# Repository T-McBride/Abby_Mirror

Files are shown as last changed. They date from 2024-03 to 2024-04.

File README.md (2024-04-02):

# Abby's Mirror: About
<p>
Dear Abby,

This project is the collective effort of your Aunt Jill, Uncle, Dave, Jim, Monica, and myself.<br>
May it bring you many years of joy.
</p>
<br>

<hr>

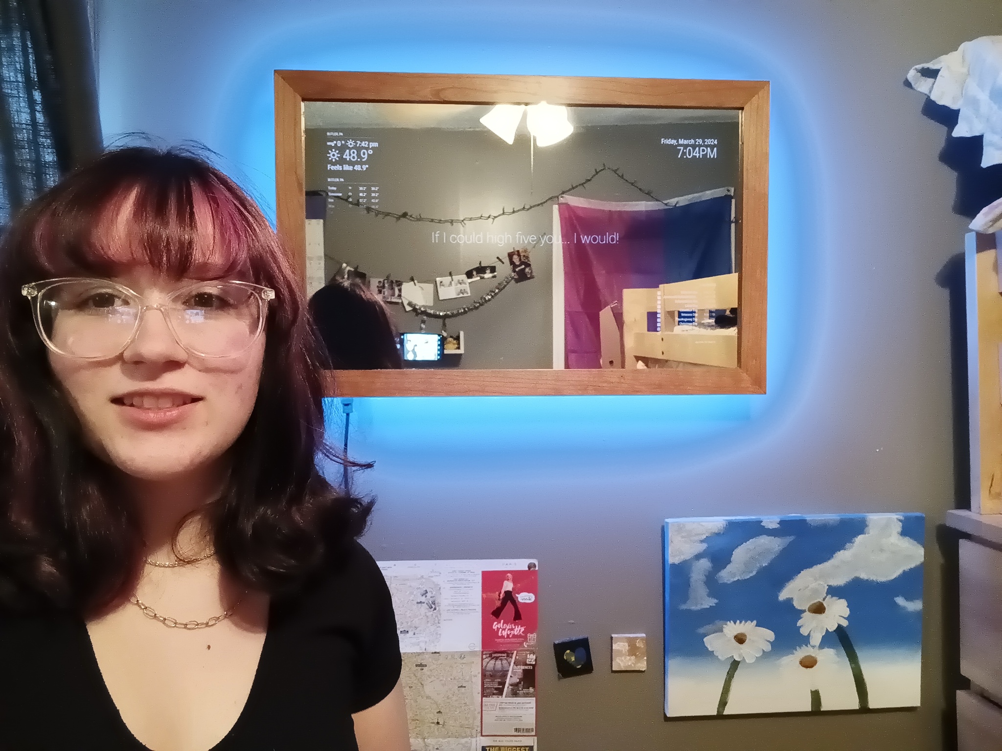
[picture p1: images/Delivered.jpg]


*pic of delivery day for posterity*

<hr>

## Pages

  * [Quick Start](./QuickStart.md) (start here to get the basics)
  * [Guide](./Guide.md) Detailed informaiton about using all features of your mirror
  * [Build Log](./BuildLog.md) This page shows a history of how your mirror came to be
  * [Print files](./Print.md) stl files of 3D printed parts used
  * The rest of this page contains basic information about your mirror.
<hr>

## Hardware
This section documents the hardware used to create your mirror.
| Object | Description | Ref | Pic | 
| :--- | :---: | :---: | :---: |
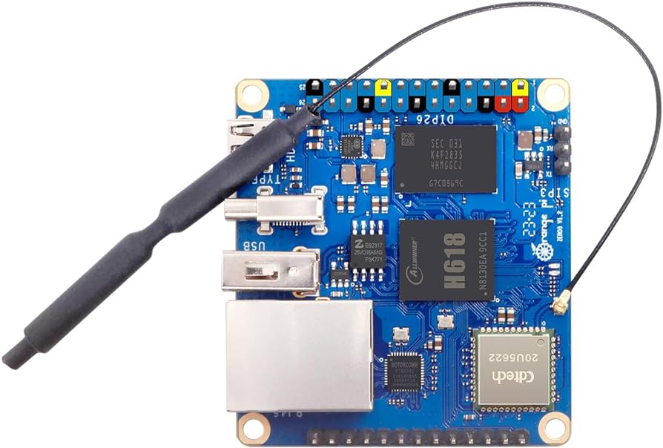
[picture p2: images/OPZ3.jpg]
| Orange Pi Zero 3  | Hardware / CPU | [Orangepi website](http://www.orangepi.org/html/hardWare/computerAndMicrocontrollers/details/Orange-Pi-Zero-3.html) |  |
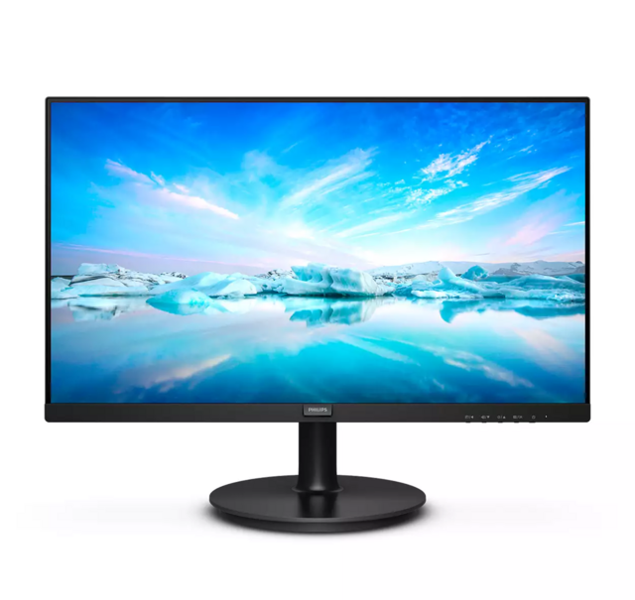
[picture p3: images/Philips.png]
| Philips 27" monitor | Monitor | [Philips V-line](https://www.usa.philips.com/c-p/271V8L_27/monitor-lcd-monitor) |  |
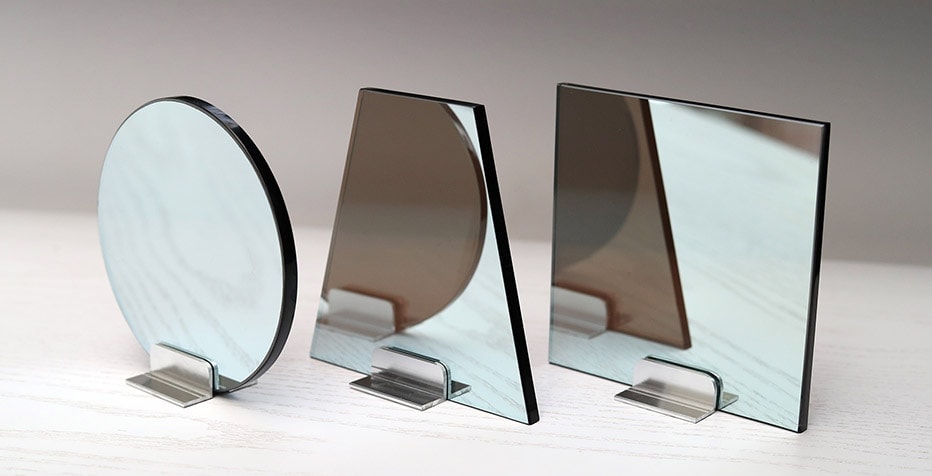
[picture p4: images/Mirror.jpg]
| One way mirror glass | Provided by Alderfer | [Alderfer](https://alderferglass.com/) |  | 
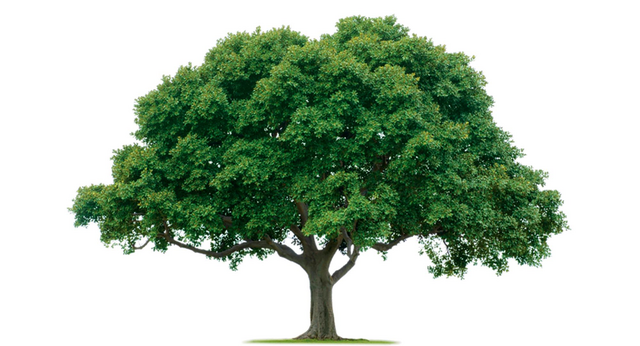
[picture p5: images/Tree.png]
| Frame | Poplar frame with Cherry trim | [trees](https://www.arborday.org/trees/treeguide) |  |  
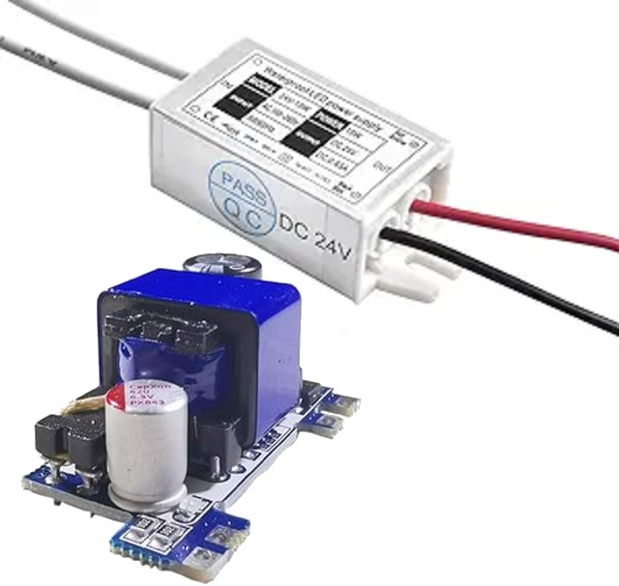
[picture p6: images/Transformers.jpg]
| Transformers | 120v to [5v & 24v] | [120v to 24v](https://www.amazon.com/24V-LED-Power-Supply-Transformer/dp/B09DKR1F71) <br> [120v to 5v](https://www.amazon.com/Converter-Module-Universal-Isolated-Switching/dp/B08ZSW2PP8) |  |
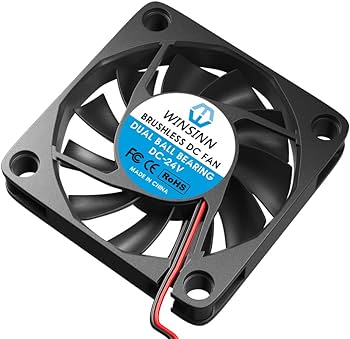
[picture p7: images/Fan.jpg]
| Fans | 24v 60mm fans | [Fans](https://www.amazon.com/WINSINN-Brushless-Computer-Motherboard-Graphics/dp/B07R3WCKCX) |  | 
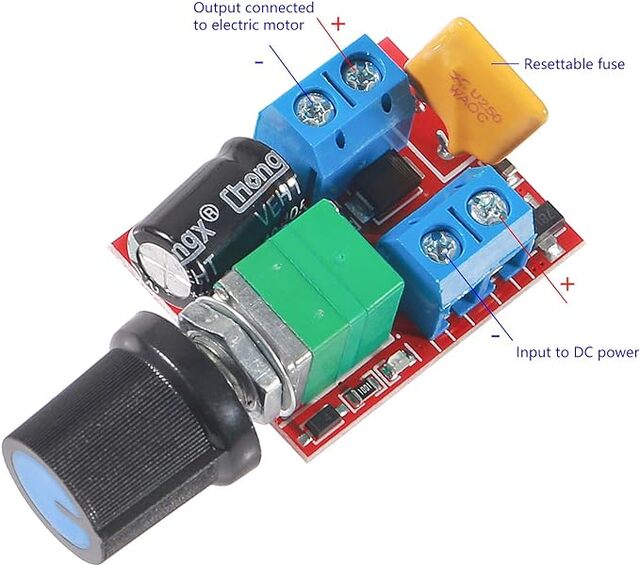
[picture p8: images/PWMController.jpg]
| Fan controller | PWM controller | [PWM Controller](https://www.amazon.com/Motor-Controller-Control-Switch-Dimmer/dp/B08T5TJWYH) |  |

<hr>

## Software
This is the software used to create and augment your mirror.
| Object | Description | Ref | 
| :--- | :--- | :--- |
| Operating System | Debian Bookworm | [Orange Pi OS Downloads](http://www.orangepi.org/html/hardWare/computerAndMicrocontrollers/service-and-support/Orange-Pi-Zero-3.html) | 
| MagicMirror | Primary application | https://magicmirror.builders/ | 
| Samba | Windows file sharing | https://www.samba.org/ |

<hr>

## Magic Mirror Config
This section describes how your mirror has been configured (default). This configuration can be chagned and customized however desired.

### Modules 
Your mirror has several modules that extend it's functionality, below is the list of currently installed modules. There are many modules available, read more about modules [via this link](https://github.com/MichMich/MagicMirror/wiki/3rd-party-modules).
| Module | Desc |  
| :--- | :--- |
| MMM-Remote | Provides a web interface to interact and manage your mirror | 
| MMM-Scheduler | Schedule module visibility, brightness, etc | 
| Weather | Current and forecast | 
| Clock | it's a clock | 
| MMM-DailyBibleVerse | Verse of the day from BibleGateway.com | 
| MMM-RAIN-MAP | Shows a radar map when it's raining | 
| Compliments Plus | Abby's favorite plugin, originally from here https://github.com/hangorazvan but appears to be abandoned.  | 
| MMM-BackgroundSlideshow | Mirror wallpaper, rotates from samba share folder | 

### Default Module Config and Layout
This section describes how the default modules are configured.
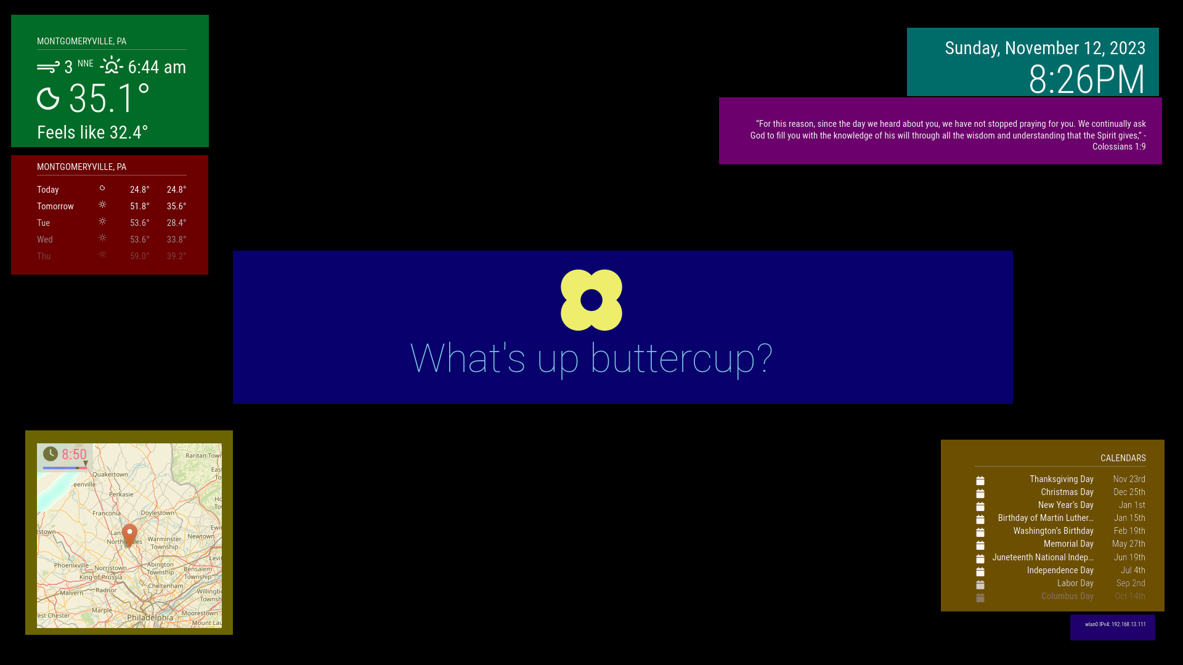
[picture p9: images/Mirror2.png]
mirror2


| Module | Location (default) | Color | Displays | 
| :--- | :--- | :--- | :--- |
| Current weather | top left | green | always |
| Forecast | top left | red | always |
| Rain Map | lower left | yellow | when raining |  
| Clock | top right | cyan | always | 
| Daily verse | top right | magenta | Sunday | 
| Compliments plus | center | blue | always |
| Calendar | lower right | orange | daily 6:00AM to 10:00PM | 
| IP address | lower right | purple | always (until turned off) |
| * | * | * | all modules dimmed to 40% at 10PM | 

Next: Read the [usage guide](Guide.md)

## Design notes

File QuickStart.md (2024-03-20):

# Abby's Mirror: Quick Start 

On the back of your mirror was a letter with a QR code that brought you hear. This letter also contained the passwords you will need as you follow this guide. 

<hr>

## Initial Startup

  1. Power the mirror via the cord, connector, and switch on the bottom of the mirror. 
  1. Once powered on the mirror application should start join the WiFi automatically, alternately you can use the LAN connector near the power connector

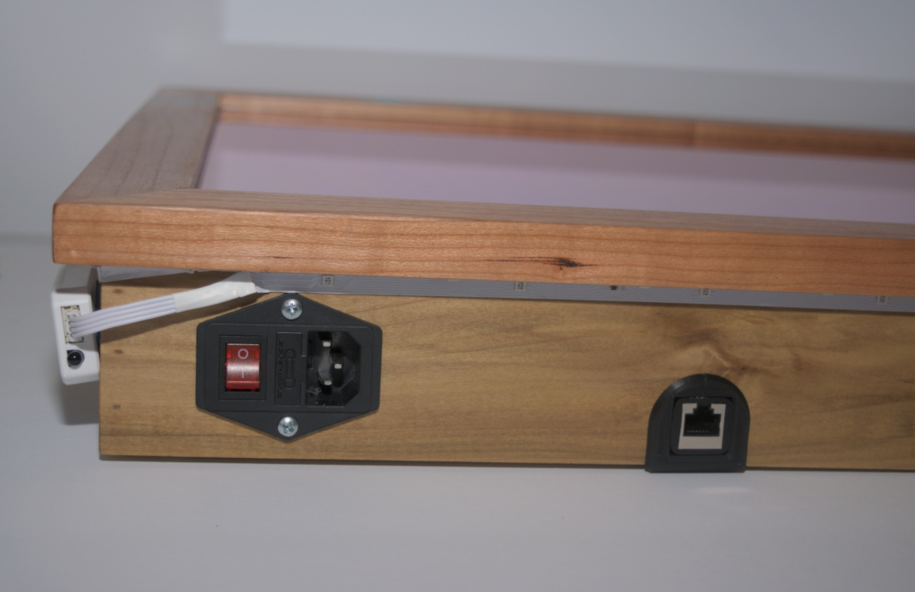
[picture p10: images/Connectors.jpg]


The mirror application should start on it's own

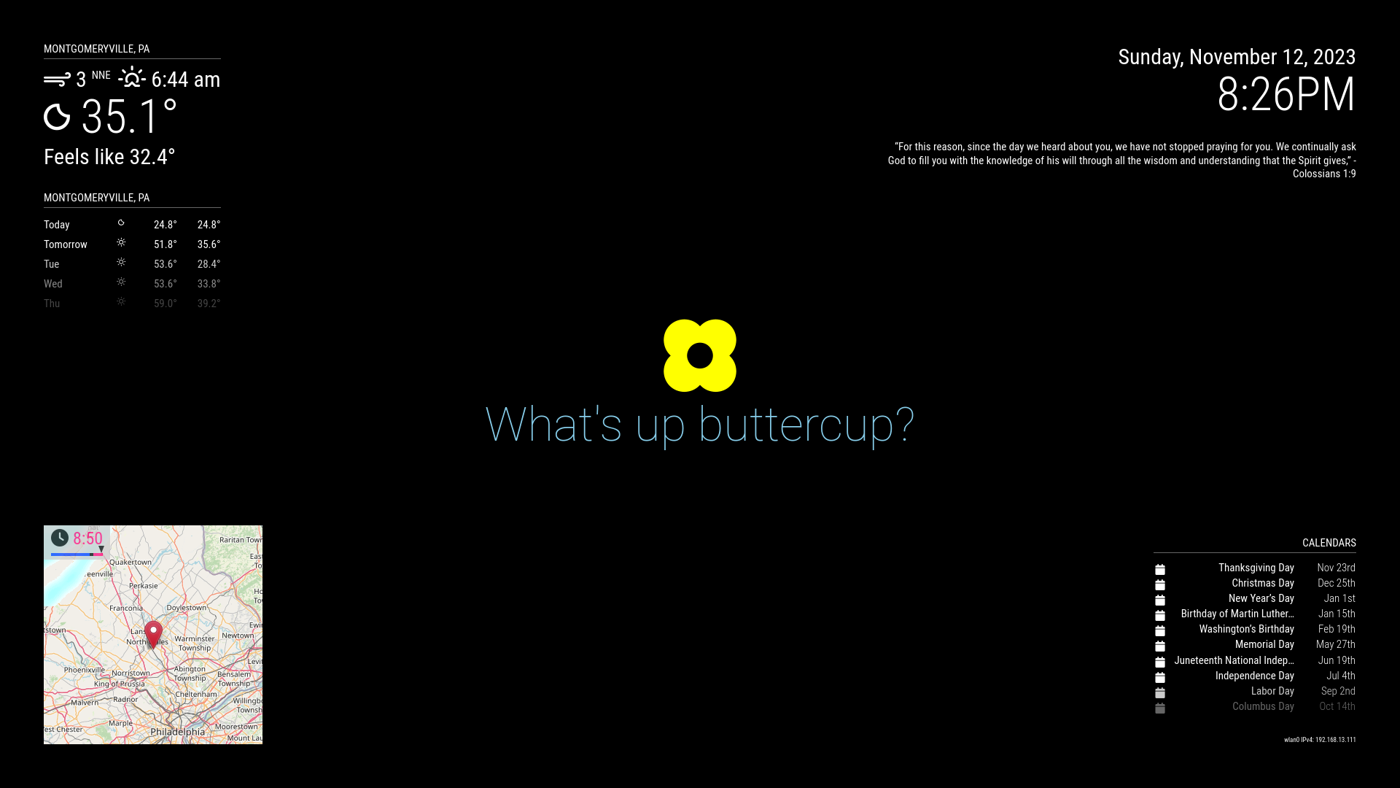
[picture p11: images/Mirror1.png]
mirror1


<hr>

## Default Module Config

Your mirror will show you different information depending upon time of day, weather etc. 

mirror2

*Read the [config page](../Guide.md) for full details on what is displayed when.* 

<hr>

## Advanced Functionality  

Once on the network the IP address will be displayed in the lower right hand corner (above purple). Use this address to access other features of your mirror as described below. 

### Web interface 

Your mirror has a web interface that allows you to do things like show/hide modules, set the brightness, turn it on/off, etc. 

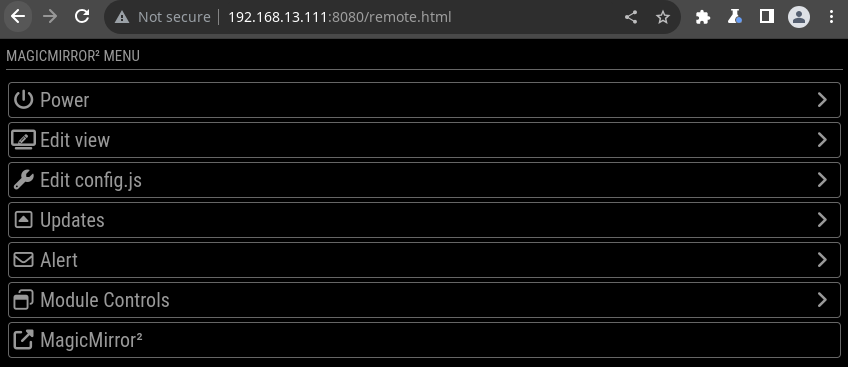
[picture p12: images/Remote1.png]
mirror


Use the IP address in conjunction with **:8080/remote.html** to find this interface from any browser on the same wifi network.  

*Note: if you have an Apple device you can also use abby_mirror.local in place of the numerical IP*

e.g.
  * http://abby_mirror.local:8080/remote.html
  * http://192.168.13.111:8080/remote.html

### Background images (file sharing)

Your mirror has the ability to display fullscreen background images. 

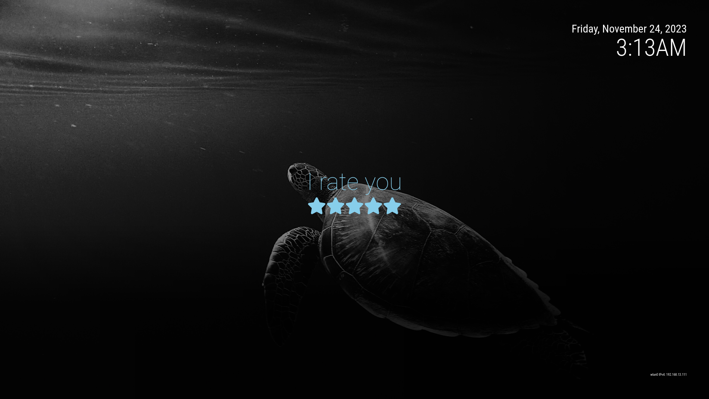
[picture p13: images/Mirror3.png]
background images


Enable the module via the remote page mentioned above. 

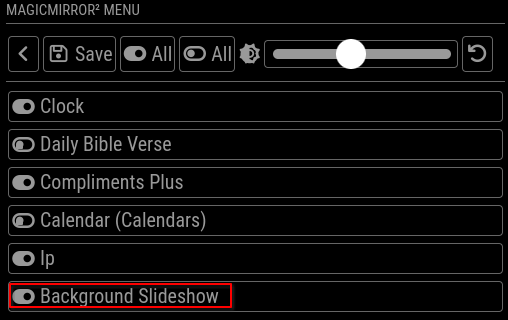
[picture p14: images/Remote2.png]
remote1


These images cycle randomly and are pulled from a shared folder. This shared folder may be accessed by any computer on the same wifi network. 

Read the [usage guide](../Guide.md) for instruction on how to upload new background images.

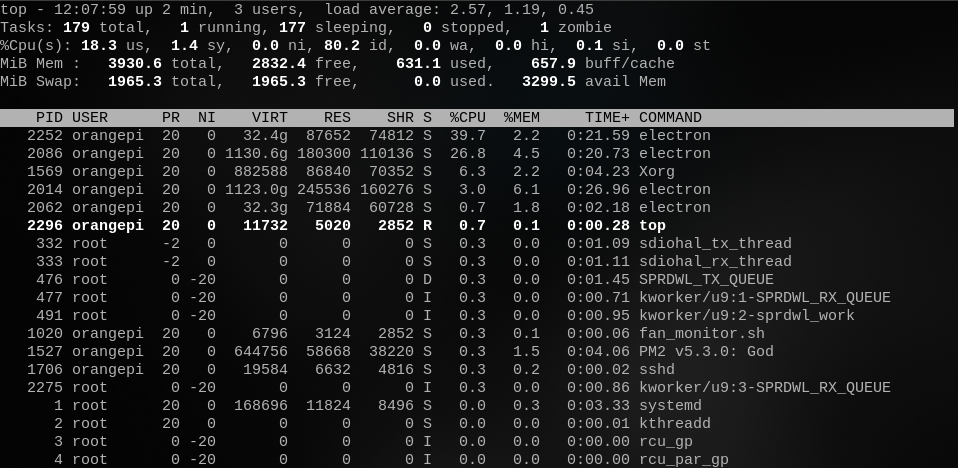
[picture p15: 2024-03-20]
images/top1.png

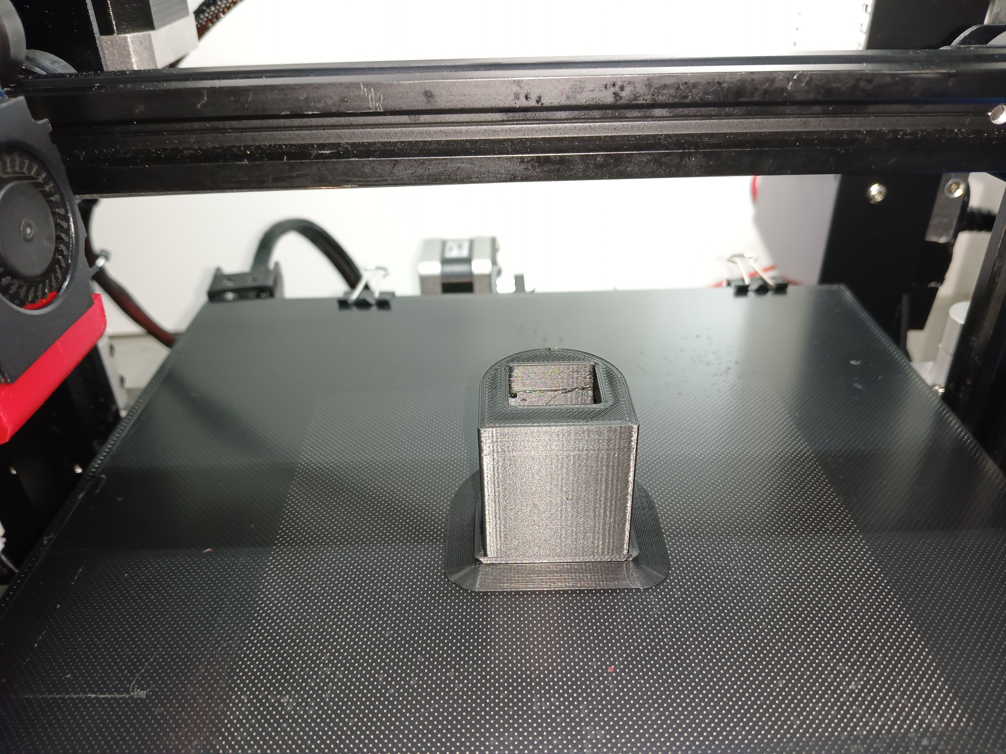
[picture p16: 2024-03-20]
images/3D1.jpg

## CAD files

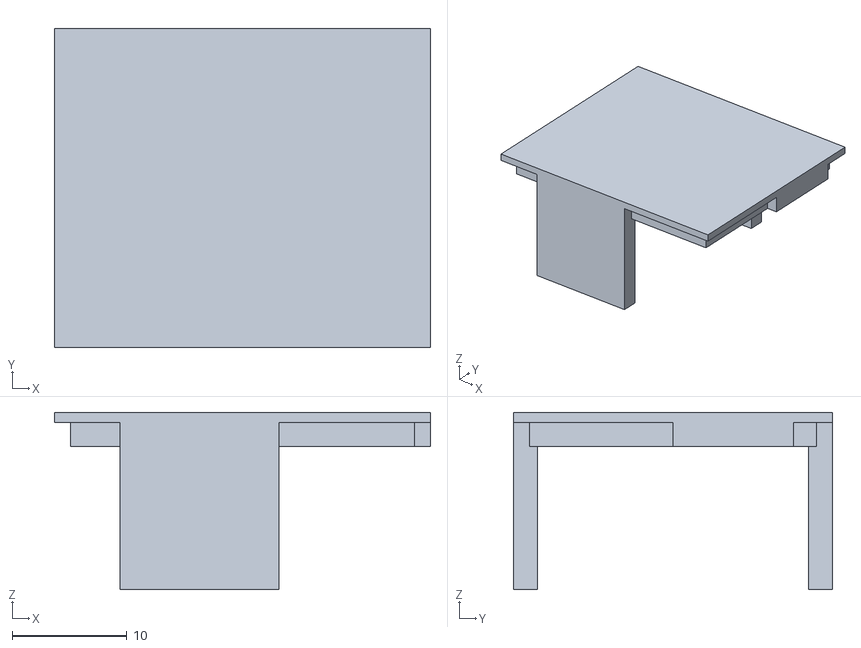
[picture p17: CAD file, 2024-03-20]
print/PWMHousingLid.stl
32.8 x 27.8 x 15.5

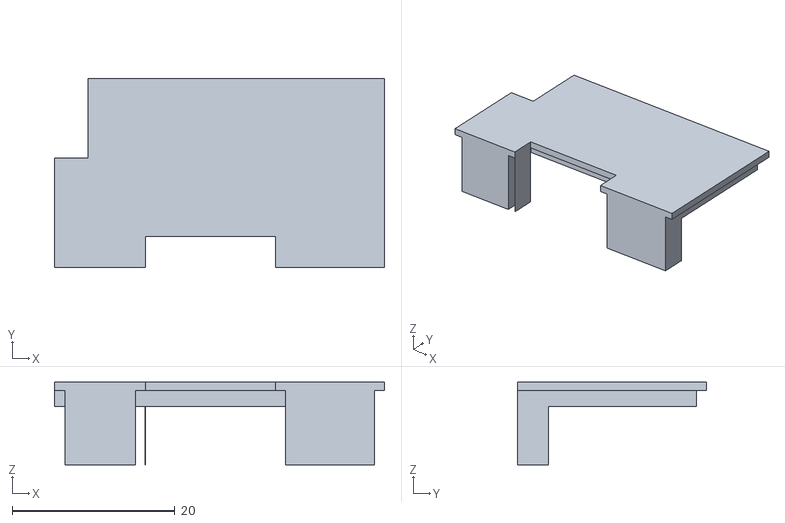
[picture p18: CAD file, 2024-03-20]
print/TransformerHousingLid.stl
40.5 x 23.2 x 10.2

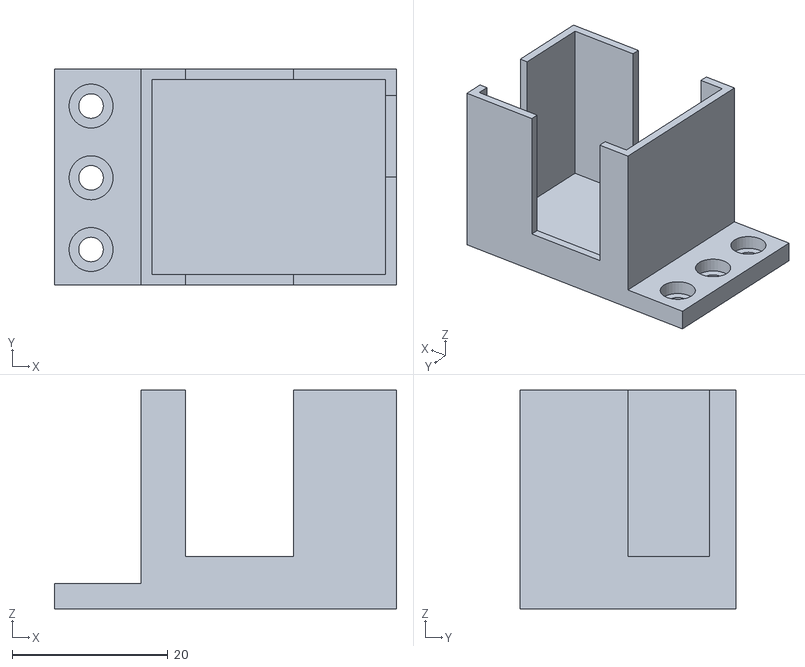
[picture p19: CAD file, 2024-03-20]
print/PWMHousing.stl
43.9 x 27.8 x 28.1

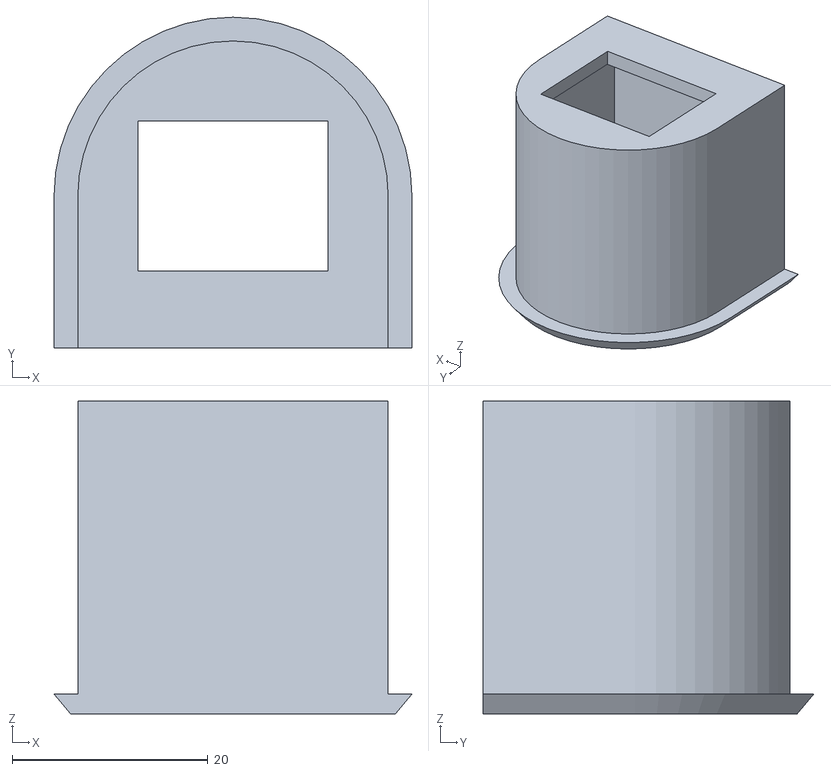
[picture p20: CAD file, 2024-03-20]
print/LAN.stl
36.6 x 33.8 x 32.0

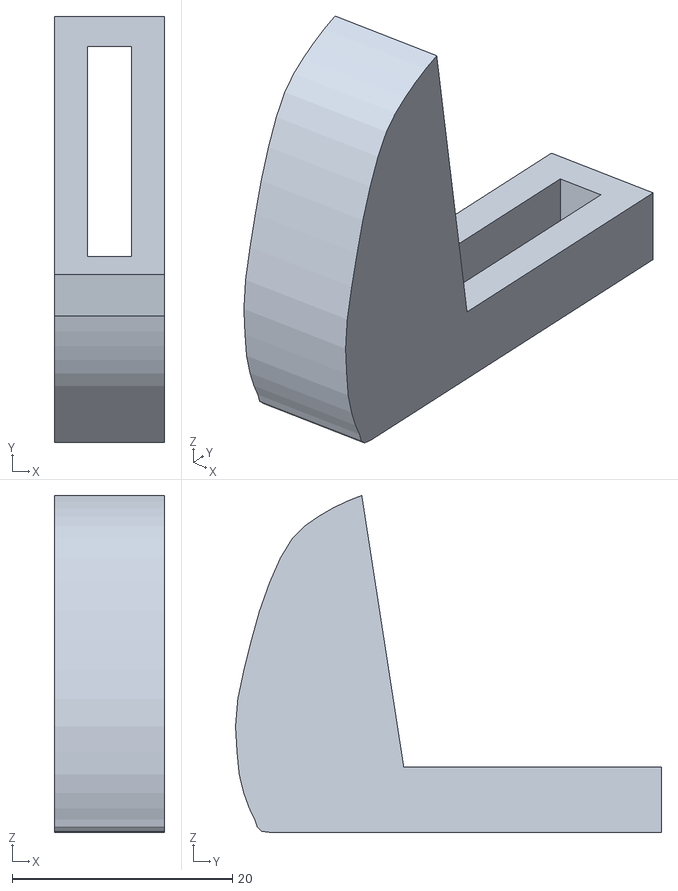
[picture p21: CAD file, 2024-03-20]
print/MonitorClamp.stl
10.00 x 38.7 x 30.6

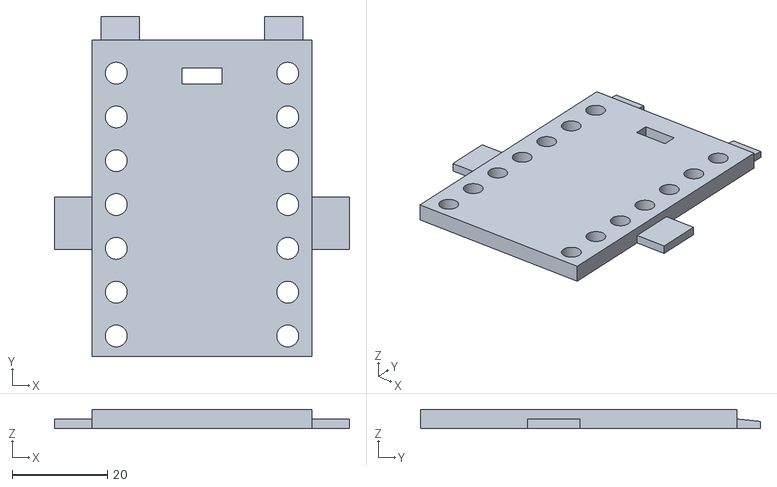
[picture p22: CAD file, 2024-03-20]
print/MonitorMountBase.stl
62.0 x 71.4 x 4.00

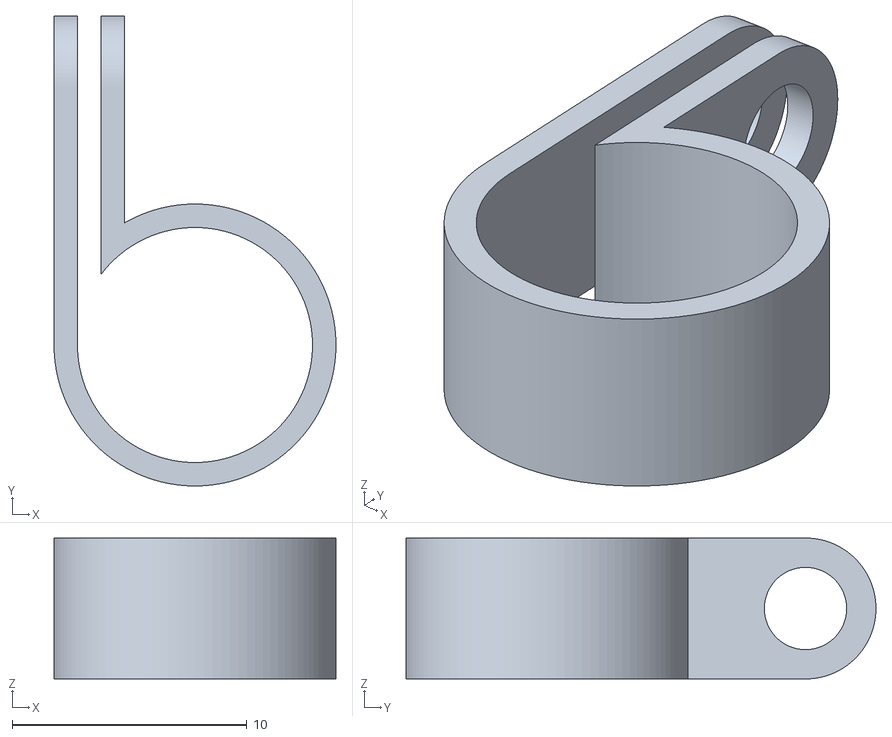
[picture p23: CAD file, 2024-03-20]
print/CableClamp_10_11.stl
12.0 x 20.0 x 6.00

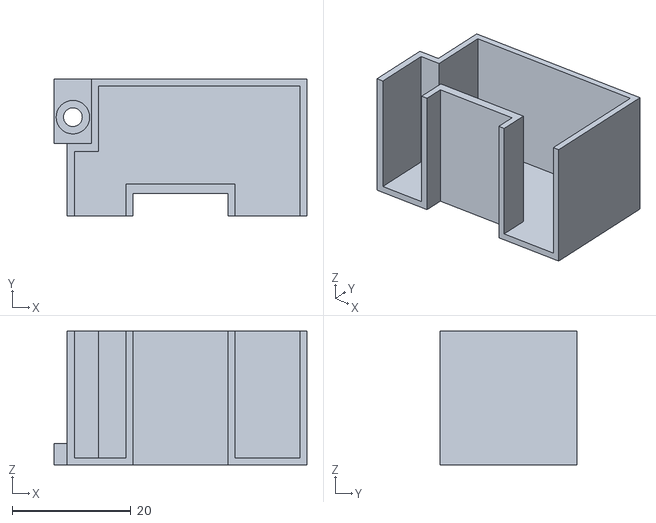
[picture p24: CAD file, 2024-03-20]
print/TransformerHousing.stl
42.7 x 23.2 x 22.6

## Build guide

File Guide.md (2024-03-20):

# Abby's Mirror: Usage Guide

This page describes how to use the mirror and all of it's features. 

<hr>

## Power and Network

Power on the mirror via the connector and switch located on the bottom of the mirror. 

The mirror will join known wireless networks automatically. Use the LAN connector near the power switch if needed.



*Please use the external buttons to cleanly shutdown the mirror prior to turning the switch off*

<hr>

## External Buttons

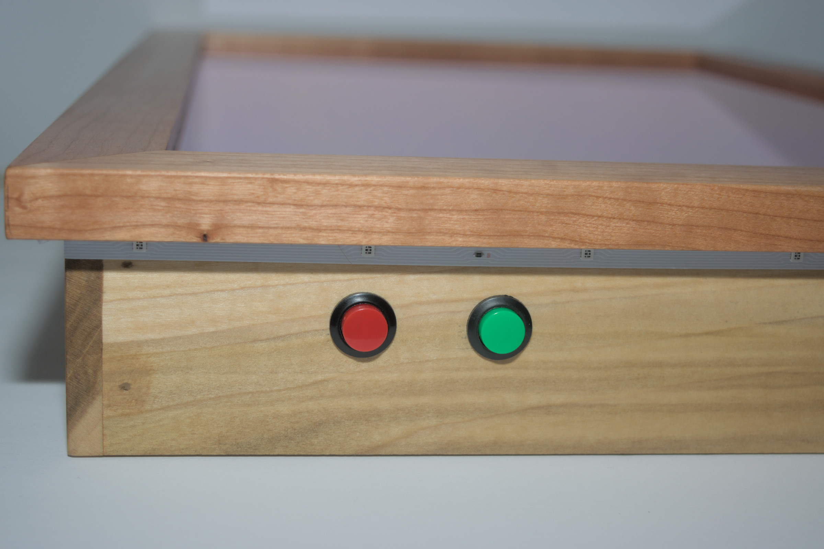
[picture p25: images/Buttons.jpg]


  * Press the green button to restart the mirror application only
  * Press the red button to shutdown the mirror 
    * The screen will fill with text, when it says Target shutdown reached it's OK to turn the power off

<hr>

## LEDs 

Your mirror has LEDs, use the included remote. 

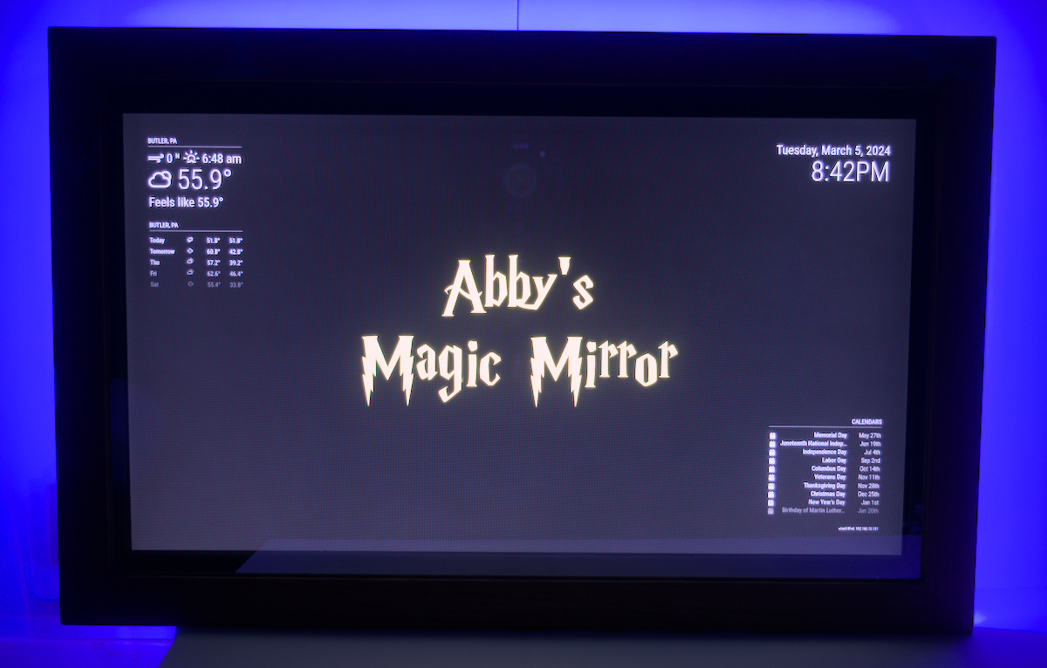
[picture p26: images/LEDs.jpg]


<hr>

## General Usage 
The mirror should boot and find the network on it's own. Once on the network the IP address will be displayed in the lower right hand corner. 

*The IP address is how you "find" the mirror on your network. You'll need this address to use things like the web interface and file sharing.*

mirror

### Web Interface

Your mirror has a web control interface that you you can access while on the same local network (wifi). Using this interface you can configure which modules are shown, set the brightness of the mirror, send it alerts, turn it off, etc. 

mirror

Access the mirrors remote webpage via the **ip address** + **:8080/remote.html** 

This will likely work too on everything but Android **abby_mirror.local:8080/remote.html** 

e.g. 
  * [http://abbymirror.local:8080/remote.html](http://abbymirror.local:8080/remote.html)
  * http://192.168.13.111:8080/remote.html

Read more about this module here https://github.com/Jopyth/MMM-Remote-Control

### Background Images

Your mirror can display background images as a slideshow. 

mirror3

Enable this module via the Web Interface to use. (Located under the edit view option)

remote

Place images into the *Background Images* shared folder to include them in the Background images rotation. 

## Advanced Usage

Items below this point will require some form of authentication, use of username(s), password(s), and key(s) that came on the letter with your mirror. 

### File Sharing 

Your mirror works as network file server. You should be able to find it from another PC by searching "Network". 

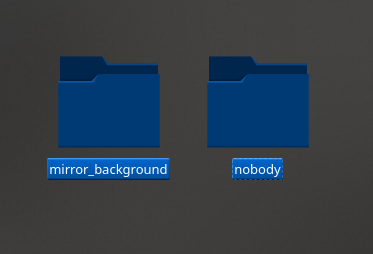
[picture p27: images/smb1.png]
smb


Use the file share user name and password that came in the letter with your mirror.

### SSH 

You can access the operating system of your mirror via a standard SSH connection. Use the SSH username and password provided in the letter that came with your mirror. 

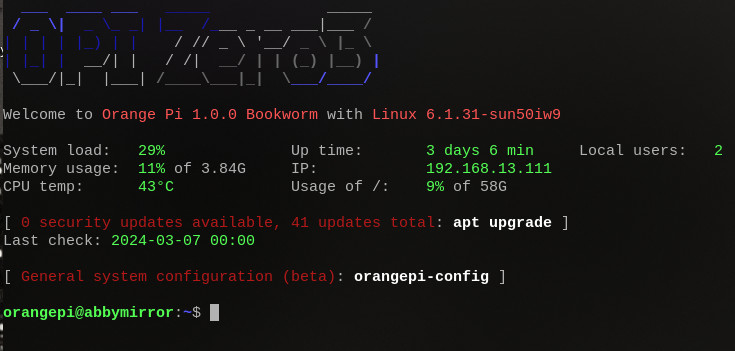
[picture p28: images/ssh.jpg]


Read more about SSH here: https://www.openssh.com/

### API 

Your mirror has a fully functional API that you can use to build your own applications or control however you please. 

e.g.
 

Use the api key that came in the letter with your mirror. 

Read more about the API config here: https://documenter.getpostman.com/view/6167403/Rzfni66c

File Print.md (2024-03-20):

# Abby's Mirror: Print Files

This page is just an index of custom 3D printed parts used in construction in case replacements are needed.  

| Desc | Image | 
| :---: | :---: |
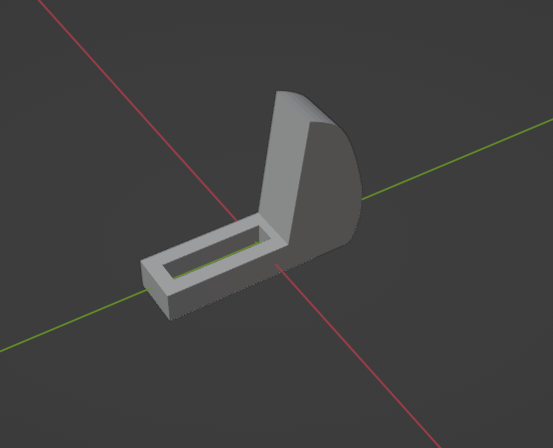
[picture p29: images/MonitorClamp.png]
| [Monitor clamps](./print/MonitorClamp.stl) |  | 
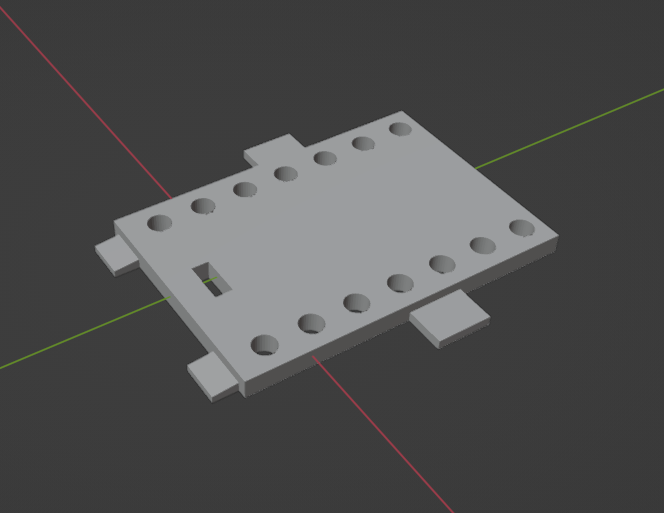
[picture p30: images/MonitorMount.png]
| [Monitor mount plate](./print/MonitorMountBase.stl) |  | 
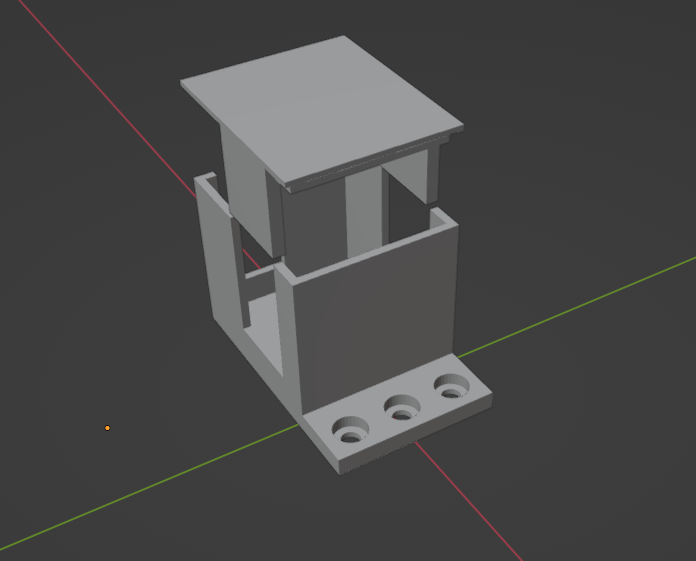
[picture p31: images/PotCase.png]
| [PWM housing](./print/PWMHousing.stl) <br> [PWM Housing Lid](./print/PWMHousingLid.stl) |   | 
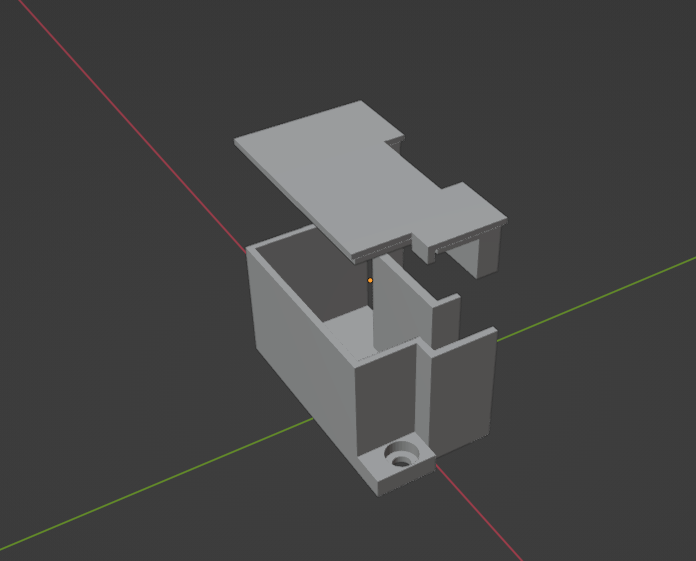
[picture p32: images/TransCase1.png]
| [5v transformer housing](./print/TransformerHousing.stl) <br> [5v transformer housing lid](./print/TransformerHousingLid.stl) |  | 
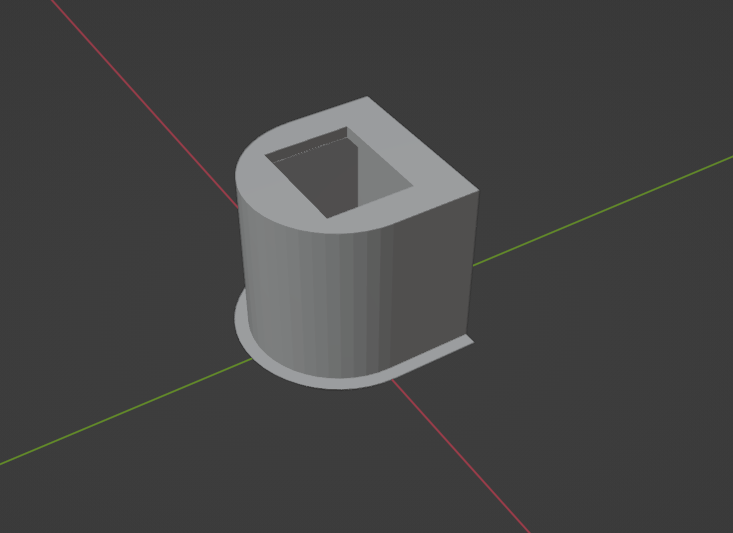
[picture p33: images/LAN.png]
| [LAN](./print/LAN.stl) |  | 
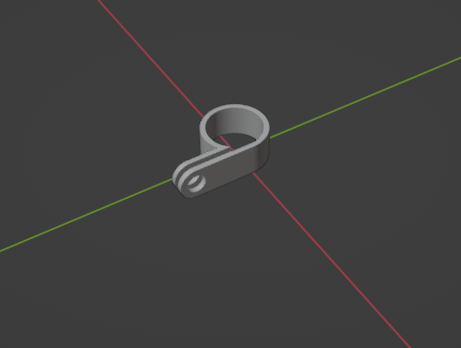
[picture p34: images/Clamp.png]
| [Clamp](./print/CableClamp_10_11.stl) |  |

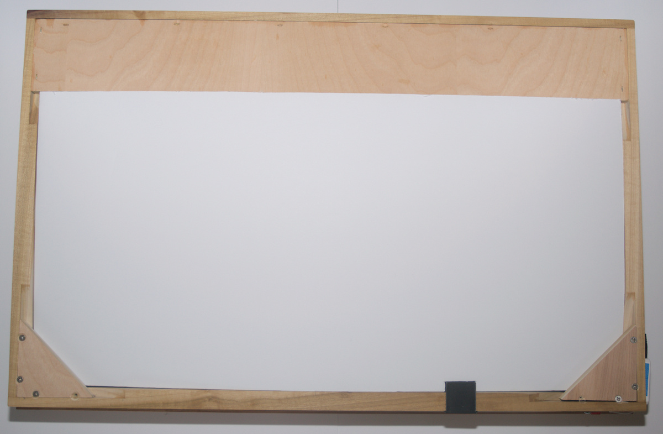
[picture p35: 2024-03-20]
images/FinalAssemble1.jpg

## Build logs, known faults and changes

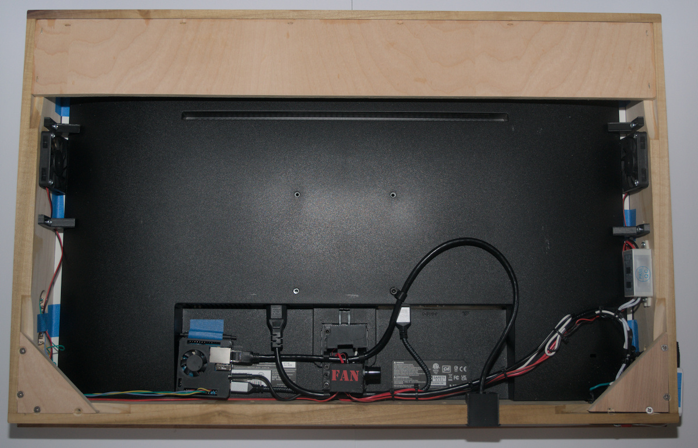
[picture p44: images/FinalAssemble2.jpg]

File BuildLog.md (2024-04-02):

# Abby's Mirror: Build Log

This page is a rough build log some steps may have been ommited but this should get you pointed in the right direction.

<hr>

## Operating System

Install orangepi version of headless Debian (bookworm)

    dd if=[start.img] of=/dev/sdx bs=8M && sync

Boot the device, first boot will take a moment as the FS expands etc. 
Login via ssh or local tty to complete the remaining. 

### Update passwords

Update the passwords for the orangepi and root accounts (recommended)

    passwd 
    sudo su 
    passwd

### Fix Vim

    vim ~/.vimrc
        set tabstop     =2
        set softtabstop =2
        set shiftwidth  =1
        set expandtab
        syntax on

### Swap out the sources and sources.d stuff because Huawei and shady**

(recommended)

    vim /etc/apt/sources.list
        deb http://deb.debian.org/debian bookworm main non-free-firmware
        deb-src http://deb.debian.org/debian bookworm main non-free-firmware

        deb http://deb.debian.org/debian-security/ bookworm-security main non-free-firmware
        deb-src http://deb.debian.org/debian-security/ bookworm-security main non-free-firmware

        deb http://deb.debian.org/debian bookworm-updates main non-free-firmware
        deb-src http://deb.debian.org/debian bookworm-updates main non-free-firmware

    rm /etc/apt/sources.d/docker.list

### Disable Docker

Telemetry, docker not used

    systemctl disable docker containerd

## Update everything

Update the core system

    apt update 
    apt upgrade
    
### Get some needed stuff

    sudo apt install xinit xserver-xorg x11-xserver-utils samba avahi-daemon npm

<hr>

## Magic Mirror

Clone the repo, install dependencies, create a basic confg / configure

    git clone https://github.com/MichMich/MagicMirror
    sudo apt install libatk1.0-0 libgtk-3-0 libgbm1 libnss3
    cd MagicMirror
    npm install
    cp ./config/config.js.sample ./config/config.js

Add more modules:
  * Compliments Plus
  * Rain map
  * Remote
  * BackgroundSlideshow
  * Upload some pro fonts 

### Own /dev/tty2 at boot

Take ownership of tty2 at boot so that X can be started manually for a single app

as root:

    crontab -e
        @reboot chown orangepi:orangepi /dev/tty2 

Run this command now if you need to test before rebooting. 

### Whip up a simple xinitrc
    
Disables screensaver and starts X and mirror on primary display

    vim ~/.xinitrc
        xset dpms 0 0 0 && xset s noblank  && xset s off
        cd ./MagicMirror
        DISPLAY=:0 npm start

### Create a startup script for PM2

    vim mm.sh
        startx
    chmod +x mm.sh

### Install PM2

    sudo npm install -g pm2
    pm2 start mm
    pm2 save

<hr>

## Checkpoint

At this point you should have an auto starting Magic mirror on headless Debian with minial X.

How minimal?

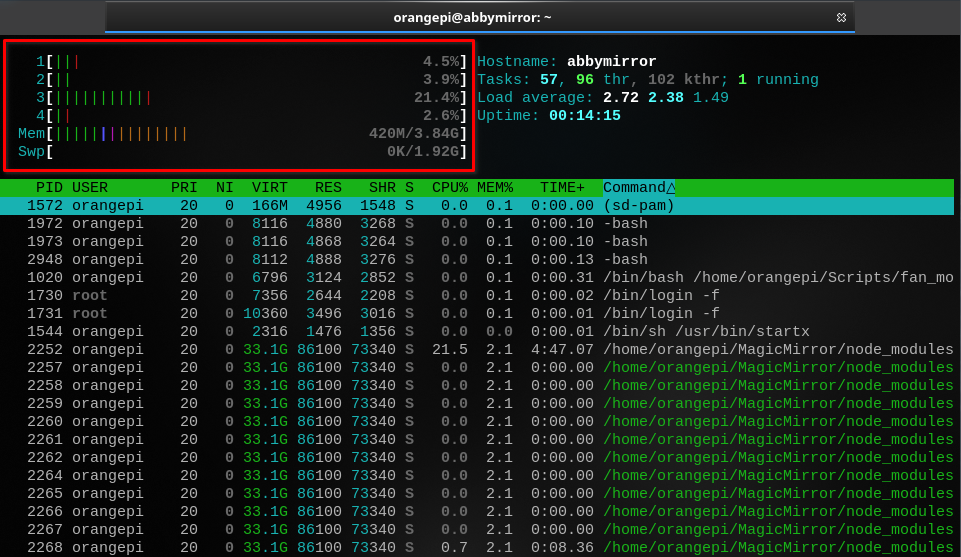
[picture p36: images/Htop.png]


<hr>

## Extra Credit

### GPIO cooling fan 

Wire up an NPN transistor as shown to use as a driver. 

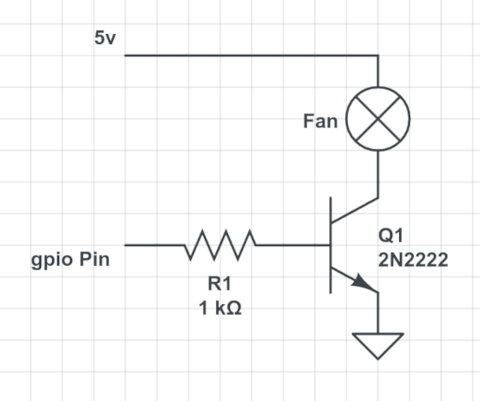
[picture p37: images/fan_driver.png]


e.g. 2n222 with 1K(ish) base resistor.

create a driver script and start at boot e.g. below 

    #!/bin/bash
    fanPin="6"
    onTemp=45000
    offTemp=40000
    gpio mode $fanPin out 
    getTemp() {
        while IFS= read -r line
        do
            #echo $line
        done < '/sys/devices/virtual/thermal/thermal_zone0/temp'
    }
    while true 
    do      
        temp=$(getTemp)
        #echo $temp
        if [ $temp -gt $onTemp ]; then 
            state=1
            gpio write $fanPin $state
        fi
        if [ $temp -lt $offTemp ]; then 
            state=0
            gpio write $fanPin $state
                
        fi
        sleep 5
    done    

Run the script at boot...

    crontab -e 
        @reboot /home/orangepi/Scripts/fan_monitor.sh >/dev/null 2>&1 & disown 

Please note this example uses gpio vs a python library because keeping python up to date is a full time job. I also learned there is this whole internet nerd fight about accessing hardware via the file system userspace or kernel. 

### GPIO inputs 
Input switches were wired as shown and a simple poll script was created. 

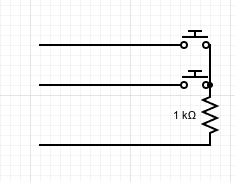
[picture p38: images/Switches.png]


*bottom lead is commong ground others go to switch pins*

```
#!/bin/bash

shutdownPin=9
restartPin=10

gpio mode $shutdownPin in
gpio mode $shutdownPin up

gpio mode $restartPin in
gpio mode $restartPin up

# Wait for startup etc to finish
sleep 30

while [ 1 -eq 1 ]
do
  if [ $(gpio read 9) -eq "0" ]; then
    sudo shutdown -h 0
    #echo "shutdown"
    #echo "shutdown" > ~/Scripts/input_monitor.log
  fi
  if [ $(gpio read 10) -eq "0" ]; then
    . ~/.bashrc
    cd ~/MagicMirror
    pm2 restart mm &> input_monitor.log
    #echo "restart mm" >> ~/Scripts/input_monitor.log
  fi
  sleep .2
done
```

Start the script at boot. 
```
crontab -e
    @reboot ~/Scripts/input_monitor.sh >/dev/null 2>&1 & disown
```
<hr>

## Frame 

Full credit to Jim Deaver for making a beautiful frame from Poplar and Cherry. 

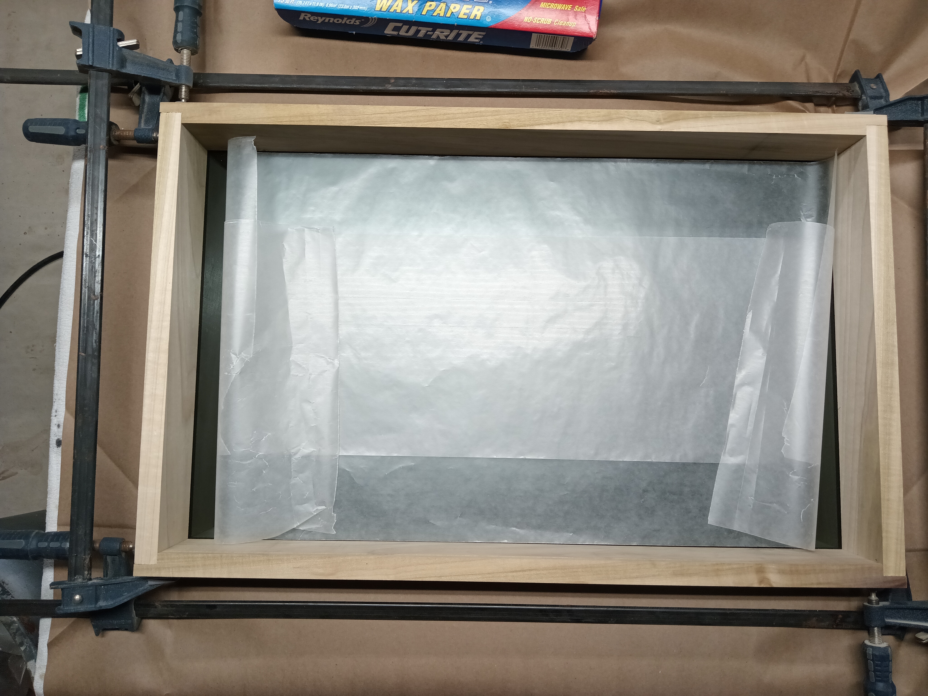
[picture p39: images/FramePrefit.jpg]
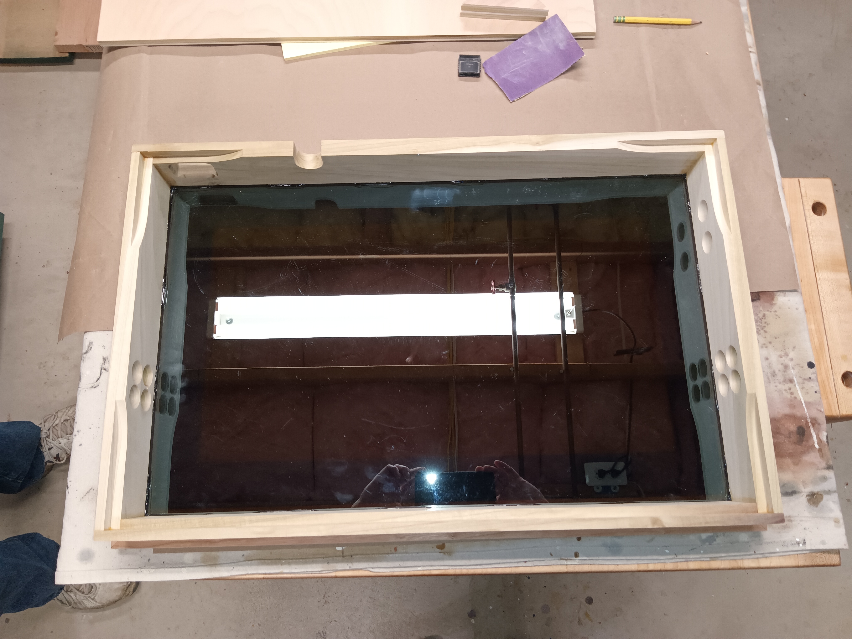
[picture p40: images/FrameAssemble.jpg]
|  |  |  |
| :---: | :---: | :---: |
| Glass fitted | Parts layout | Frame assembled |

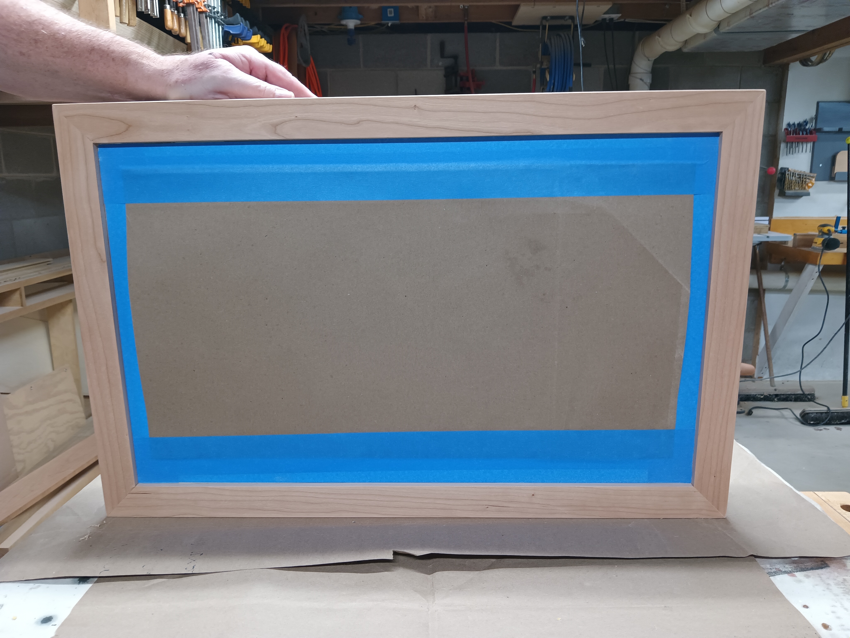
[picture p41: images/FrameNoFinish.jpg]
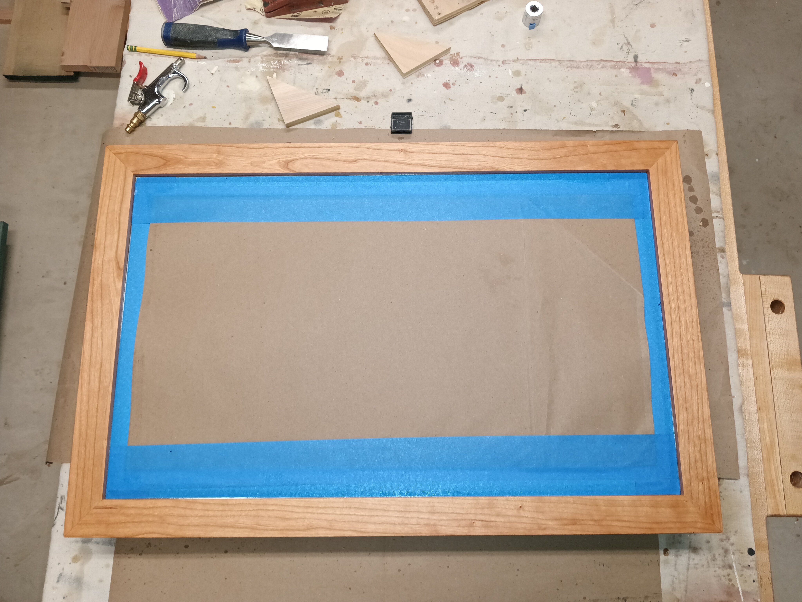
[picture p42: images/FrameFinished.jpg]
|  |  | 
| :---: | :---: |
| Unfinished | Finished |

<hr>

## Additional 

Some 3D Printed parts were created to help keep things tidy. 

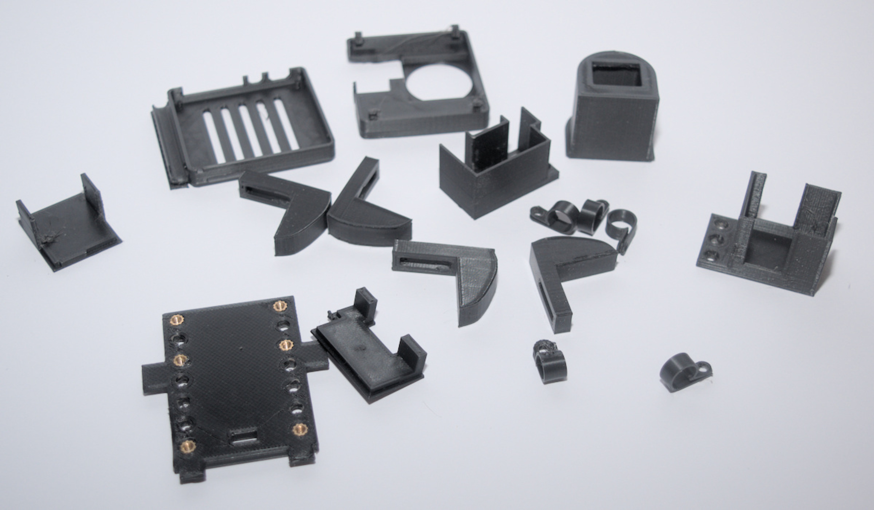
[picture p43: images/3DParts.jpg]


*Files can be found [here](../Print.md) if needed* 

<hr>

## Assembly Process 

 

<hr>

## Internals
